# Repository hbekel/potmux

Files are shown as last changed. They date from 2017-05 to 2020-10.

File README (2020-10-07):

PotMux -- Hardware add-on to reroute C64 control port pot lines
(C) 2020 Henning Liebenau <henning.liebenau@protonmail.com>

This project is currently in early beta state and things may
change without notice.

The PotMux is a small hardware add-on for the C64 that allows the user
to optionally route the control port potentiometer lines to a
destination other than the SID. It is mainly intended to be used with
the Keyman64 for the purpose of mapping additional joystick buttons
connected to the potentiometer lines to user defined keystrokes.

For details about the hardware, see ./hardware/README.txt

The potmux utility contained in this archive can be used to prefix an
existing C64 program with a specific potmux configuration for the
Keyman64. The resulting program will first configure the Keyman64
using its serial interface connected to the tapeport lines "Cassette
Sense" and "Cassette Data" and then run the original program.

Usage: potmux [<option>...] <program> [<button|switch>...]

Options:
         -h, --help           : print this help text
         -v, --version        : print version information
         -o, --outfile <file> : output file (default: stdout)

Arguments:
         <program> : C64 program file to patch
         <button>  : route a joystick button to a key
         <switch>  : specify enable line and state

Example:
         potmux -o patched.prg game.prg a0:on b1:space

Assuming that the PotMux EN line is connected to the keyman line on
port a bit 0, the "a0:on" switch specification assures that the potmux
will be enabled by pulling that line low. And assuming that one of the
PotMux button output lines is connected to the keyman control line on
port b bit 1, the "b1:space" will configure the keyman to send a space
key press when the corresponding button is pressed.

LICENSING

Hardware and Software licensed under MIT-style licensing schemes

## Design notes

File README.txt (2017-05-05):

PotMux Rev.2 -- Pot line multiplexer for the C64
Copyright Henning Bekel 2016.
Licensed under CERN OSH v.1.2 (see LICENSE.txt)

In the C64 there is a 4066 IC that selects two of the four analog
lines from the control ports (POTAX, POTAY, POTBX, POTBY) to the two
analog input lines of the SID, depending on the setting of the CIAs
PA6 and PA7 line. This allows the programmer to choose which paddle
pair or mouse to read from the SID by setting the CIA lines
accordingly.

This board replaces the 4066 and adds the ability to alternatively
route the four analog control port lines somewhere else instead.

When the boards enable line (/EN) is high, the control port lines are
routed to the SID as usual, selected by PA6 and PA7.

When /EN is low, the control port lines POTAX, POTAY, POTBX and POTBY
are routed to the pins A1, A2, B1 and B2.

On older C64 mainboards, the 4066 replaced by this board is annotated
with U28. On the newer 250469 revision, the 4066 is annotated with
U18.

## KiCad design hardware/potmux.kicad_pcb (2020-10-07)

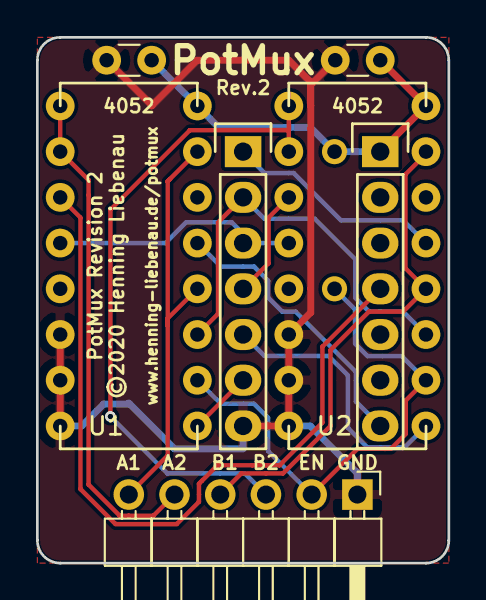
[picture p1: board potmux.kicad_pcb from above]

Board: 2 copper layers, 22.9 x 29.2 mm, 8 parts (1 on the bottom side), 15 nets.

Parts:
C1, C2: 100n; C_Disc_D3.0mm_W1.6mm_P2.50mm
P1: SOCKET_LEFT; Pin_Header_Straight_1x07
P3: SOCKET_RIGHT; Pin_Header_Straight_1x07
P4: KEYMAN64; Pin_Header_Angled_1x06_Pitch2.54mm
R1: 4k7; R3
U1, U2: 4052; DIP-16_W7.62mm

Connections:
/A1: P4.6, U1.12, U1.15
/A2: P4.5, U1.1, U1.2
/B1: P4.4, U2.12, U2.15
/B2: P4.3, U2.1, U2.2
/PA6: P1.6, U1.9
/PA7: P1.5, U2.9
/POTAX: P3.7, U1.13
/POTAY: P3.4, U1.3
/POTBX: P1.1, U2.13
/POTBY: P1.4, U2.3
/POTX: P1.2, U1.11, U2.11
/POTY: P1.3, U1.4, U2.4
/~EN: P4.2, R1.2, U1.10, U2.10
GND: C1.2, C2.2, P1.7, P4.1, U1.6, U1.7, U1.8, U2.6, U2.7, U2.8
VCC: C1.1, C2.1, P3.1, R1.1, U1.16, U2.16

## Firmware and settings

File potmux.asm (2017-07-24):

// -*- mode: kasm -*-        

.import source "serial.h"

.macro incw(addr) {
        inc addr
        bne done
        inc addr+1
done:   
}
        
:BasicUpstart2(main)

main:   sei

open:   jsr serial.open
        
a:      ldx #$00
        lda #$00
        jsr map

b:      ldx #$00
        lda #$00
        jsr map

c:      ldx #$00
        lda #$00
        jsr map

d:      ldx #$00
        lda #$00
        jsr map
                
e:      lda #Command.set
        jsr serial.write

        lda #$00
        jsr serial.write

        lda #$00
        jsr serial.write
        
close:  jsr serial.close

copy: {
        ldx #$00
loop:   lda boot,x
        sta $0334,x
        inx
        cpx #boot.end-boot
        bne loop

        jmp $0334
}
        
.import source "serial.asm"	                
        
map: {  pha
        txa
        pha
        
        lda #Command.map
        jsr serial.write
        pla
        jsr serial.write
        pla
        jsr serial.write
        rts
}

boot: {
        lda #$35
        sta $01

        ldx #$00
loop:   lda $ffff,x
        sta $0801,x
        inx
        cpx #end-$0801
        bne loop

run:    ldx #$ff
        txs
        
        lda #$37
        sta $01
        cli        

        jsr $A533
 	jsr $A659
 	jmp $A7AE
end:            
}

.print toHexString(a-$0801+2)
.print toHexString(b-$0801+2)
.print toHexString(c-$0801+2)
.print toHexString(d-$0801+2)
.print toHexString(e-$0801+2)
.print "src = " + toHexString(boot.loop+1-$0801+2)        

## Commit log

2016-10-27 Licensed under CERN OHL v.1.2
    [potmux.dsn, potmux.kicad_pcb, potmux.sch]
2016-10-28 Added pdf renderings of schematics and layout, cleaned up
    [potmux.dsn, potmux.kicad_pcb]
2016-10-28 Added README file
    [potmux.sch]
2016-11-01 Cleanups and clarifications, fixed file modes
    [potmux.sch]
2016-11-09 Improved README.txt
    [potmux.sch]
2016-11-09 Revision 1, added gerber files for production
    [potmux.kicad_pcb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]
2017-05-05 Revision 2, updated gerber files for production
    This revision moves the pin header to the bottom.
    [potmux.kicad_pcb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]
2017-05-21 Hardware: Moved into hardware directory
    [potmux.kicad_pcb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]
2017-06-03 Software: Fixed assembly code for KickAssember 3.x
    [potmux.asm]
2017-06-23 Hardware: Improved gerber Makefile, updated gerber files
    [potmux.kicad_pcb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]
2017-07-24 Avoid mapping buttons to expanded ports
2018-01-01 Improved layout, silk screen
    [potmux.sch]
2020-10-07 Changes in preparation for release
    - Changed Licenses to MIT-style licensing schemes
    - Removed files required by cern ohl
    - Rerendered schematic svg
    - Improved silkscreen, updated last name and Copyright notices
    - Adjustments for KiCAD 5.x
    - Improved Makefile
    [potmux-2020-10-06-15-06-57.sch, potmux.kicad_pcb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]

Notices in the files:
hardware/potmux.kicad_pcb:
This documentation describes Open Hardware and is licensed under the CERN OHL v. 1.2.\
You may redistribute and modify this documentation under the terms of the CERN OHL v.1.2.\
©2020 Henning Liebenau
